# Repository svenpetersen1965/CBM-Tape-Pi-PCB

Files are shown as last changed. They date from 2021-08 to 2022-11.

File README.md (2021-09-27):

# CBM-Tape-Pi-PCB
# Preliminary Release of Rev.2
This is the PCB, that I have created for <a href="https://github.com/RhinoDevel/cbmtapepi">RhinoDevel's CBM Tape Pi</a>.

It is <b>not yet tested</b> and this is only a <b>preliminary</b> release!

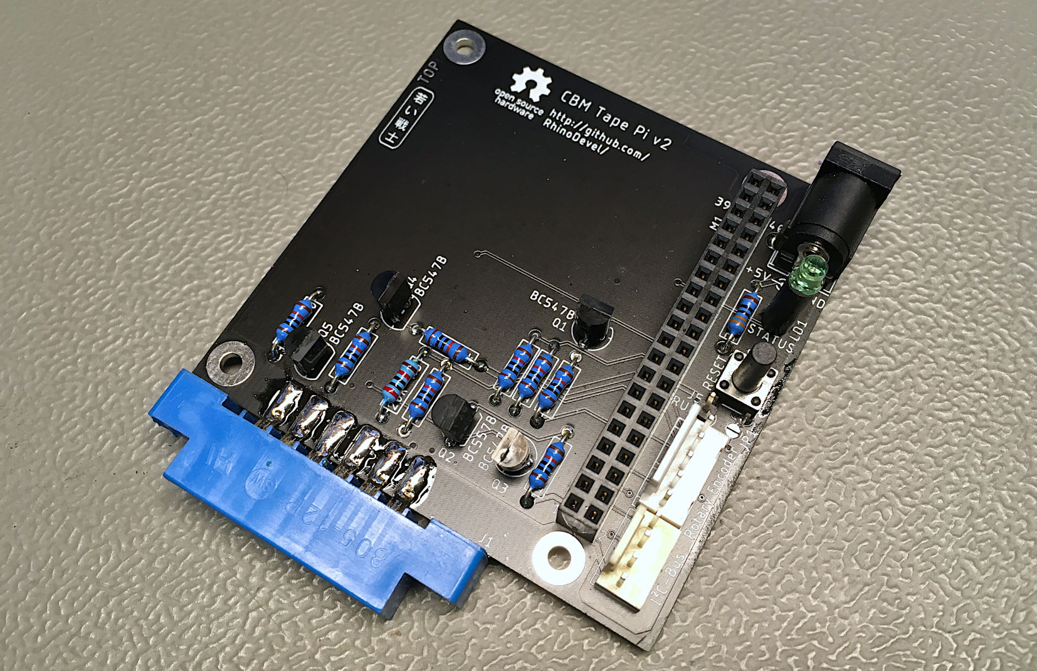
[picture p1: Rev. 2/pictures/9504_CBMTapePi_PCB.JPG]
CBM Tape Pi PCB v2


The PCB has an option for a barrel connector Power Supply. Also, for possible future software development, a rotary encode and an I²C OLED-Display can be connected. This is not yet supported.

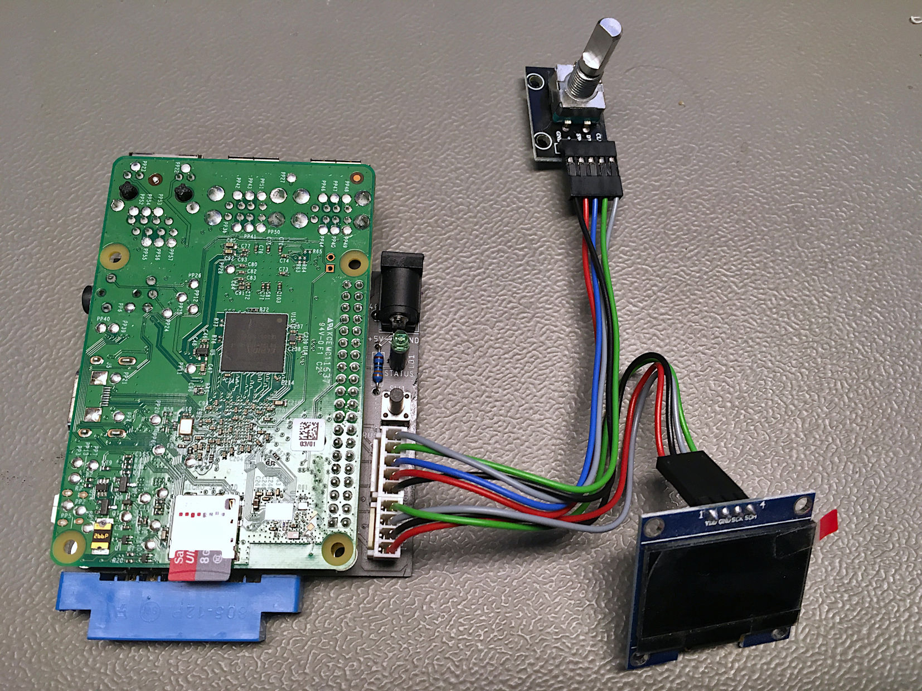
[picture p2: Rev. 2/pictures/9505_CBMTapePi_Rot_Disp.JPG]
CBM Tape Pi PCB complete


Debugging result so far:

There is a screw up with signals <b>BCM11</b>, it shoudl be connected to the collector of Q4, but the signal name is screwed up. A botch wire is required between the collector of Q4/R8 and Pin 23/BCM11 of the Raspberry Pi.

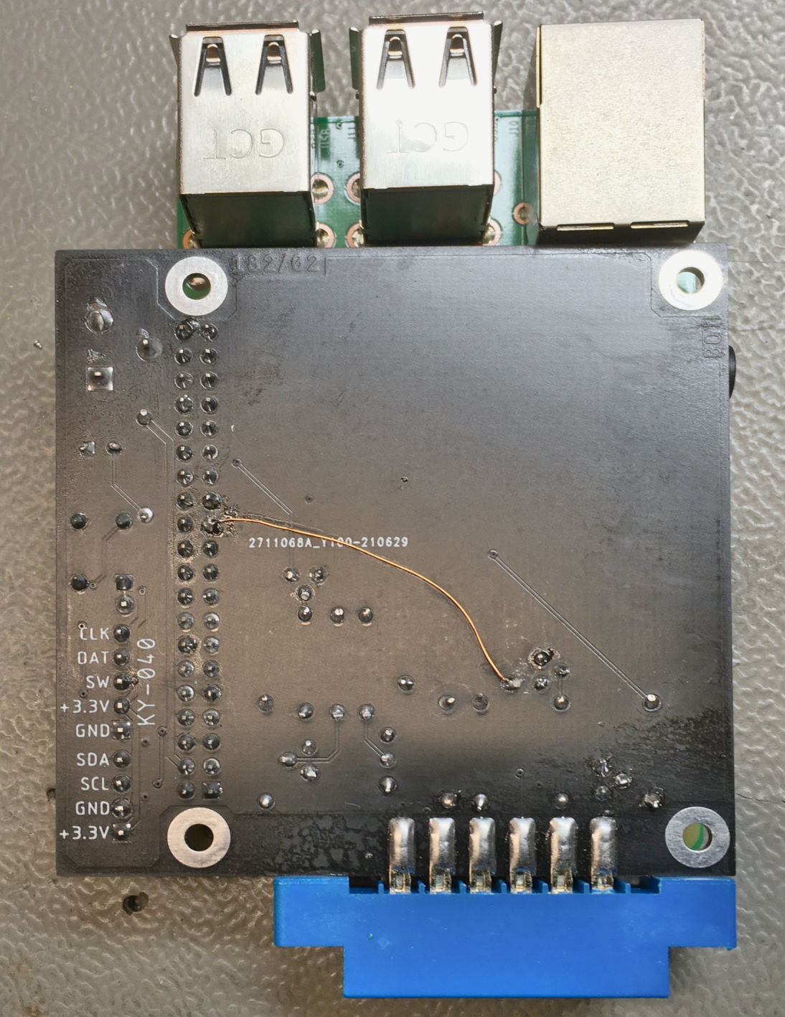
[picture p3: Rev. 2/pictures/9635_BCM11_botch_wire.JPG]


# Rev. 3
Rev. 3 fixes the bug of rev. 2. Also the dimensions have changed: the RasPi was moved 4mm away from the edge connector.

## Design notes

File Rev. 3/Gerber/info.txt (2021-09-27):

      
       Board: CBM_TAPE_PI
       Rev.:  3
  
       Files:
       ======
  
       All Gerber files are generated in extended gerber format (RS274X)
       *.TOP        : Film top copper
       *.BOT        :  -"- bottom copper
       *.STC        :  -"- top soldermask 
       *.STS        :  -"- bottom soldermask
       *.PLC        :  -"- silk screen top
       *.PLS        :  -"- silk screen bottom
       *.DK         : Drills plated Through (Excellon)
       *.NDK        : Drills not plated Through (Excellon)
       *.OUT        : Board outline

       Board Size:
       ===========
       Length     :   67.0 mm
       Width      :   70.0 mm
       Thickness  :   1.6 mm
       Material   :   FR 4
       Copper     :   35 um
       Surface    :   HASL
       
       Remarks:
       ========

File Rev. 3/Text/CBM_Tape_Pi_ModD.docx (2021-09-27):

CBM Tape Pi Rev. 3

Module Description

# Introduction

This is the PCB hardware for RhinoDevel’s CBM Tape Pi project. It is a slight enhancement of the schematic that can be found in his github repository http://github.com/RhinoDevel/

The PCB is suitable to hold a Raspberry Pi *A, *B and zero (three mounting holes on the baseboard).

The Reset button SW1 is connected to J5, a pin header/solder pad for being connected to the RUN connector (pin 1/square pad) on the Raspberry Pi. Since the position is not fix on every model, this can be accomplished with a cable/dupont connector. Alternatively, the Reset button connects to BCM4 (close solder bridge JP1).

The extras are the barrel connector J2 for a Raspberry Pi power supply (it can be used instead of the fragile USB micro-B connector on the Raspberry Pi itself). Alternatively, a pin header or KF2510/Molex kk 2.54 connector can be installed.

For future developments a rotary encoder and an I²C display (+3.3V supply voltage) can be installed. As of September 2021, both are not yet supported. Refer to RhinoDevel’s repository.

# Connectors

## J1 – CBM Cassette Port

2x6 edge connector (3.96mm pitch)

Pin | Signal | Pin | Signal
1 | GND | A | GND
2 | n.c. | B | n.c.
3 | n.c. | C | Motor
4 | n.c. | D | Read
5 | n.c. | E | Write
6 | n.c. | F | Sense

n.c.: not connected

## J2 – Raspberry Pi Power Supply

2.1/5.5mm barrel connector

Pin | Signal
inner | +5V
outer | GND

## J3 – I²C Display

KF2510/Molex KK 2.54mm, 4 pins

Pin | Signal
1 | +3.3V
2 | GND
3 | SCL
4 | SDA

## J4 – Rotary Encode

KF2510/Molex KK 2.54mm, 5 pins

The pin out is according to the wide spread rotary encoder module KY-040, which can be found on ebay, AliExpress and several online shops.

Pin | Signal
1 | GND
2 | +3.3V
3 | Switch
4 | Data
5 | Clock

## J5 – Reset Switch

Pin header, 1 pin

Pin | Signal
1 | /RESET

To be connected to the RUN header on the Raspberry Pi.

## J6 – Alternative Power Supply

KF2510/Molex KK 2.54mm, 2 pins

Pin | Signal
1 | +5V
2 | GND

## M1 -Raspberry Pi Connector

A 2x20 Pin receptible, assembled on the solder side of the PCB.

Pin | GPIO | Signal | Comment
1 | - | +3.3V | Supply voltage (output)
2 | - | +5V | Supply voltage (input)
3 | SDA | SDA (I²C) | I²C-Bus (display)
4 | - | +5V | Supply voltage (input)
5 | SCL | SCL (I²C) | I²C-Bus (display)
6 | - | GND | Ground
7 | 4 | BCM4 | /Reset , Optional (close JP1)
8 | - | n.c. | -
9 | - | GND | Ground
10 | - | n.c. | -
11 | 17 | BCM17 | Status LED (active HIGH)
12 | 18 | n.c. | -
13 | 27 | ROT_SW | Rotary Encoder Switch
14 | - | GND | Ground
15 | 22 | BCM22 | Motor (input)
16 | 23 | ROT_DATA | Rotary Encoder Data
17 | - | +3.3V | Supply voltage (output)
18 | 24 | ROT_CLK | Rotary Encoder Clock
19 | 10 | BCM10 | Read (output, active HIGH)
20 | - | GND | Ground
21 | 9 | BCM9 | Sense (ouput, inverted)
22 | - | n.c. | -
23 | 11 | BCM11 | Write (input, active LOW)
24 | - | n.c. | -
25 | - | GND | Ground
26 | - | n.c. | -
27 | - | n.c. | -
28 | - | n.c. | -
29 | - | n.c. | -
30 | - | GND | Ground
31 | - | n.c. | -
32 | - | n.c. | -
33 | - | n.c. | -
34 | - | GND | Ground
35 | - | n.c. | -
36 | - | n.c. | -
37 | - | n.c. | -
38 | - | n.c. | -
39 | - | GND | Ground
40 | - | n.c. | -

# Revision History

## Rev. 2

- Prototype with one botch wire

## Rev. 3

- Botch wire for BCM11 fixed
- The Raspberry Pi has been moved 4mm away from the edge connector (collision on a VIC-20)
- One mounting hole for Raspberry Pi zero added
- J6 added

CBM_Tape_Pi_ModD.docx 27.09.2021 13:16 Drafted by Sven Petersen Page 2 of 2 Doc.-No.: 182-6-01-03

CBM_Tape_Pi_ModD.docx 27.09.2021 13:16 Drafted by Sven Petersen Page 1 of 1 Doc.-No.: 000-6-00-00

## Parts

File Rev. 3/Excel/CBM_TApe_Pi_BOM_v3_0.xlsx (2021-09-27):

RhinoDevel: CBM Tape Pi Rev. 3
Bill of Material Rev. 3.0
Pos. | Qty | Value | Footprint | Ref.-No. | Comment
1 | 1 | 182-2-01-03 | 2 Layer | PCB Rev. 3 | 2 layer, Cu 35µ, HASL, 70.0mm x 67.0mm, 1.6mm FR4
2 | 1 | 3mm/green | 3MM | LD1 | standard 3mm LED
3 | 1 | KF2510/4p header | 6410-4P | J3 | option: KF2510 or MOLEX 6410/22-27-2041
4 | 1 | KF2510/5p header | 6410-5P | J4 | option: KF2510 or MOLEX 6410/22-27-2051
5 | 8 | 10k | R-10 | R1, R4, R5, R6, R7, R8, R9, R10 | metal film resistor, 10% or better
6 | 1 | 20k | R-10 | R3 | metal film resistor, 10% or better
7 | 1 | 330R | R-10 | R2 | metal film resistor, 10% or better
8 | 1 | KF2510/2p header | 6410-2P | J6 | option: KF2510 or MOLEX 6410/22-27-2021
9 | 4 | BC547B | TO92 | Q1, Q3, Q4, Q5 | NPN Transistor
10 | 1 | BC557B | TO92-EBC | Q2 | PNP Transistror
11 | 1 | 2x6, pitch 3.96mm | TAPEPORT | J1 | edge connector (e.g. 805 type), C64 cassette port
12 | 1 | FCR681465P | FCR681465P | J2 | Cliff, Reichelt: CLIFF FCR681465P, tme.eu: FCR681465P
13 | 1 | JTP-1130 | JTP-1130 | SW1 | 6mm x 6mm tact switch, e.g. Namae Electronics, e.g. Reichelt TASTER 9303
14 | 1 | 1 pin header | 1,2MM_R | J5 | 1 pin header (for dupont wire)
15 | 1 | RASPBERRYPI | PI_HAT_40P_UPSIDEDOWN | M1 | Raspberry Pi zero or other
16 | 1 | MPE 094-2-040 |  | (M1) | MPE, e.g. Reichelt MPE 094-2-040

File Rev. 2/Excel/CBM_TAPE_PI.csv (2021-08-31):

Qty | Value | Device | Package | Parts | Description
1 |  | 3MM | 3MM | LD1
1 |  | 6410-4P | 6410-4P | J3 | 6410/22-27-2041
1 |  | 6410-5P | 6410-5P | J4 | 6410/22-27-2051
1 |  | OPEN | CP_OP | JP1 | open Cutpad
8 | 10k | RES04 | R-10 | R1, R4, R5, R6, R7, R8, R9, R10
1 | 20k | RES04 | R-10 | R3
1 | 330R | RES04 | R-10 | R2
4 | BC547B | BC547B | TO92 | Q1, Q3, Q4, Q5 | NPN Transistor
1 | BC557B | BC557B | TO92-EBC | Q2 | PNP Transistror
1 | C64-TAPEPORT | C64-TAPEPORT | TAPEPORT | J1
1 | FCR681465P | FCR681465P | FCR681465P | J2
1 | JTP-1130 | JTP-1130 | JTP-1130 | SW1
1 | L1,2_R | L1,2_R | 1,2MM_R | J5
1 | OPEN_SOURCE_HW | OPEN_SOURCE_HW | OPENHW | U$2
1 | RASPBERRYPI-40-PIN-GPIOUSDWN | RASPBERRYPI-40-PIN-GPIOUSDWN | PI_HAT_40P_UPSIDEDOWN | M1 | 40 pin GPIO header with the footprint of a HAT

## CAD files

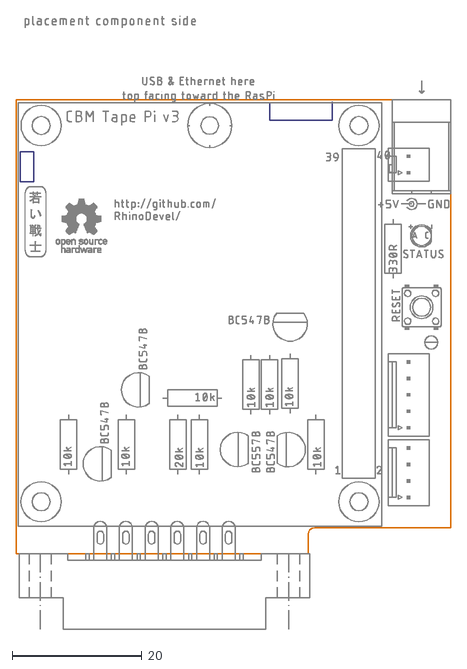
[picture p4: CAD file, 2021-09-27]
Rev. 3/dxf/CBM_TAPE_PI.dxf
67.0 x 94.5

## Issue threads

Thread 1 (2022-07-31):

5VDC Supply requirement / jumper JP1

WimWalther, 2022-07-31:
Could you please leave some comment on the requirement for an external 5VDC power supply, when a regulated 5V is already available on Pin 2 (iirc) of the CBM Cassette Tape port?

I believe jumper JP1 is also undocumented?

Would be much appreciated.

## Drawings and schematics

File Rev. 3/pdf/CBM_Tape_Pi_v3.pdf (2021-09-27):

# Project Documentation

## RhinoDevel: CBM Tape Pi

## Project number: 182

## Revision: 3

## Date: 27.09.2021

CBM_Tape_Pi_ModD.docx | | 27.09.2021 13:16
Drafted by Sven Petersen | Page 1 of 3 | Doc.-No.: 182-6-01-03

### CBM Tape Pi Rev. 3

### Module Description

## Introduction

This is the PCB hardware for RhinoDevel’s CBM Tape Pi project. It is a slight enhancement of the schematic that can be found in his github repository http://github.com/RhinoDevel/

The PCB is suitable to hold a Raspberry Pi *A, *B and zero (three mounting holes on the baseboard).

The Reset button SW1 is connected to J5, a pin header/solder pad for being connected to the RUN connector (pin 1/square pad) on the Raspberry Pi. Since the position is not fix on every model, this can be accomplished with a cable/dupont connector. Alternatively, the Reset button connects to BCM4 (close solder bridge JP1).

The extras are the barrel connector J2 for a Raspberry Pi power supply (it can be used instead of the fragile USB micro-B connector on the Raspberry Pi itself). Alternatively, a pin header or KF2510/Molex kk 2.54 connector can be installed.

For future developments a rotary encoder and an I²C display (+3.3V supply voltage) can be installed. As of September 2021, both are not yet supported. Refer to RhinoDevel’s repository.

## Connectors

### J1 – CBM Cassette Port

2x6 edge connector (3.96mm pitch)

Pin | Signal | Pin | Signal
1 | GND | A | GND
2 | n.c. | B | n.c.
3 | n.c. | C | Motor
4 | n.c. | D | Read
5 | n.c. | E | Write
6 | n.c. | F | Sense
n.c.: not connected

### J2 – Raspberry Pi Power Supply

2.1/5.5mm barrel connector

Pin | Signal
inner | +5V
outer | GND

### J3 – I²C Display

KF2510/Molex KK 2.54mm, 4 pins

Pin Signal
1 +3.3V

### 2 GND 3 SCL 4 SDA

CBM_Tape_Pi_ModD.docx | | 27.09.2021 13:16
Drafted by Sven Petersen | Page 2 of 3 | Doc.-No.: 182-6-01-03

### J4 – Rotary Encode

KF2510/Molex KK 2.54mm, 5 pins

The pin out is according to the wide spread rotary encoder module KY-040, which can be found on ebay, AliExpress and several online shops.

Pin Signal
1 GND
2 +3.3V
3 Switch
4 Data
5 Clock

### J5 – Reset Switch

Pin header, 1 pin

Pin Signal
1 /RESET

To be connected to the RUN header on the Raspberry Pi.

### J6 – Alternative Power Supply

KF2510/Molex KK 2.54mm, 2 pins

Pin Signal
1 +5V
2 GND

### M1 -Raspberry Pi Connector

A 2x20 Pin receptible, assembled on the solder side of the PCB.

Pin | GPIO | Signal | Comment
1 | - | +3.3V | Supply voltage (output)
2 | - | +5V | Supply voltage (input)
3 | SDA | SDA (I²C) | I²C-Bus (display)
4 | - | +5V | Supply voltage (input)
5 | SCL | SCL (I²C) | I²C-Bus (display)
6 | - | GND | Ground
7 | 4 | BCM4 | /Reset , Optional (close JP1)
8 | - | n.c. | -
9 | - | GND | Ground
10 | - | n.c. | -
11 | 17 | BCM17 | Status LED (active HIGH)
12 | 18 | n.c. | -
13 | 27 | ROT_SW | Rotary Encoder Switch
14 | - | GND | Ground
15 | 22 | BCM22 | Motor (input)
16 | 23 | ROT_DATA | Rotary Encoder Data
17 | - | +3.3V | Supply voltage (output)
18 | 24 | ROT_CLK | Rotary Encoder Clock
19 | 10 | BCM10 | Read (output, active HIGH)

CBM_Tape_Pi_ModD.docx | | 27.09.2021 13:16
Drafted by Sven Petersen | Page 3 of 3 | Doc.-No.: 182-6-01-03
Pin | GPIO | Signal | Comment
20 | - | GND | Ground
21 | 9 | BCM9 | Sense (ouput, inverted)
22 | - | n.c. | -
23 | 11 | BCM11 | Write (input, active LOW)
24 | - | n.c. | -
25 | - | GND | Ground
26 | - | n.c. | -
27 | - | n.c. | -
28 | - | n.c. | -
29 | - | n.c. | -
30 | - | GND | Ground
31 | - | n.c. | -
32 | - | n.c. | -
33 | - | n.c. | -
34 | - | GND | Ground
35 | - | n.c. | -
36 | - | n.c. | -
37 | - | n.c. | -
38 | - | n.c. | -
39 | - | GND | Ground
40 | - | n.c. | -

## Revision History

### Rev. 2

- Prototype with one botch wire
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

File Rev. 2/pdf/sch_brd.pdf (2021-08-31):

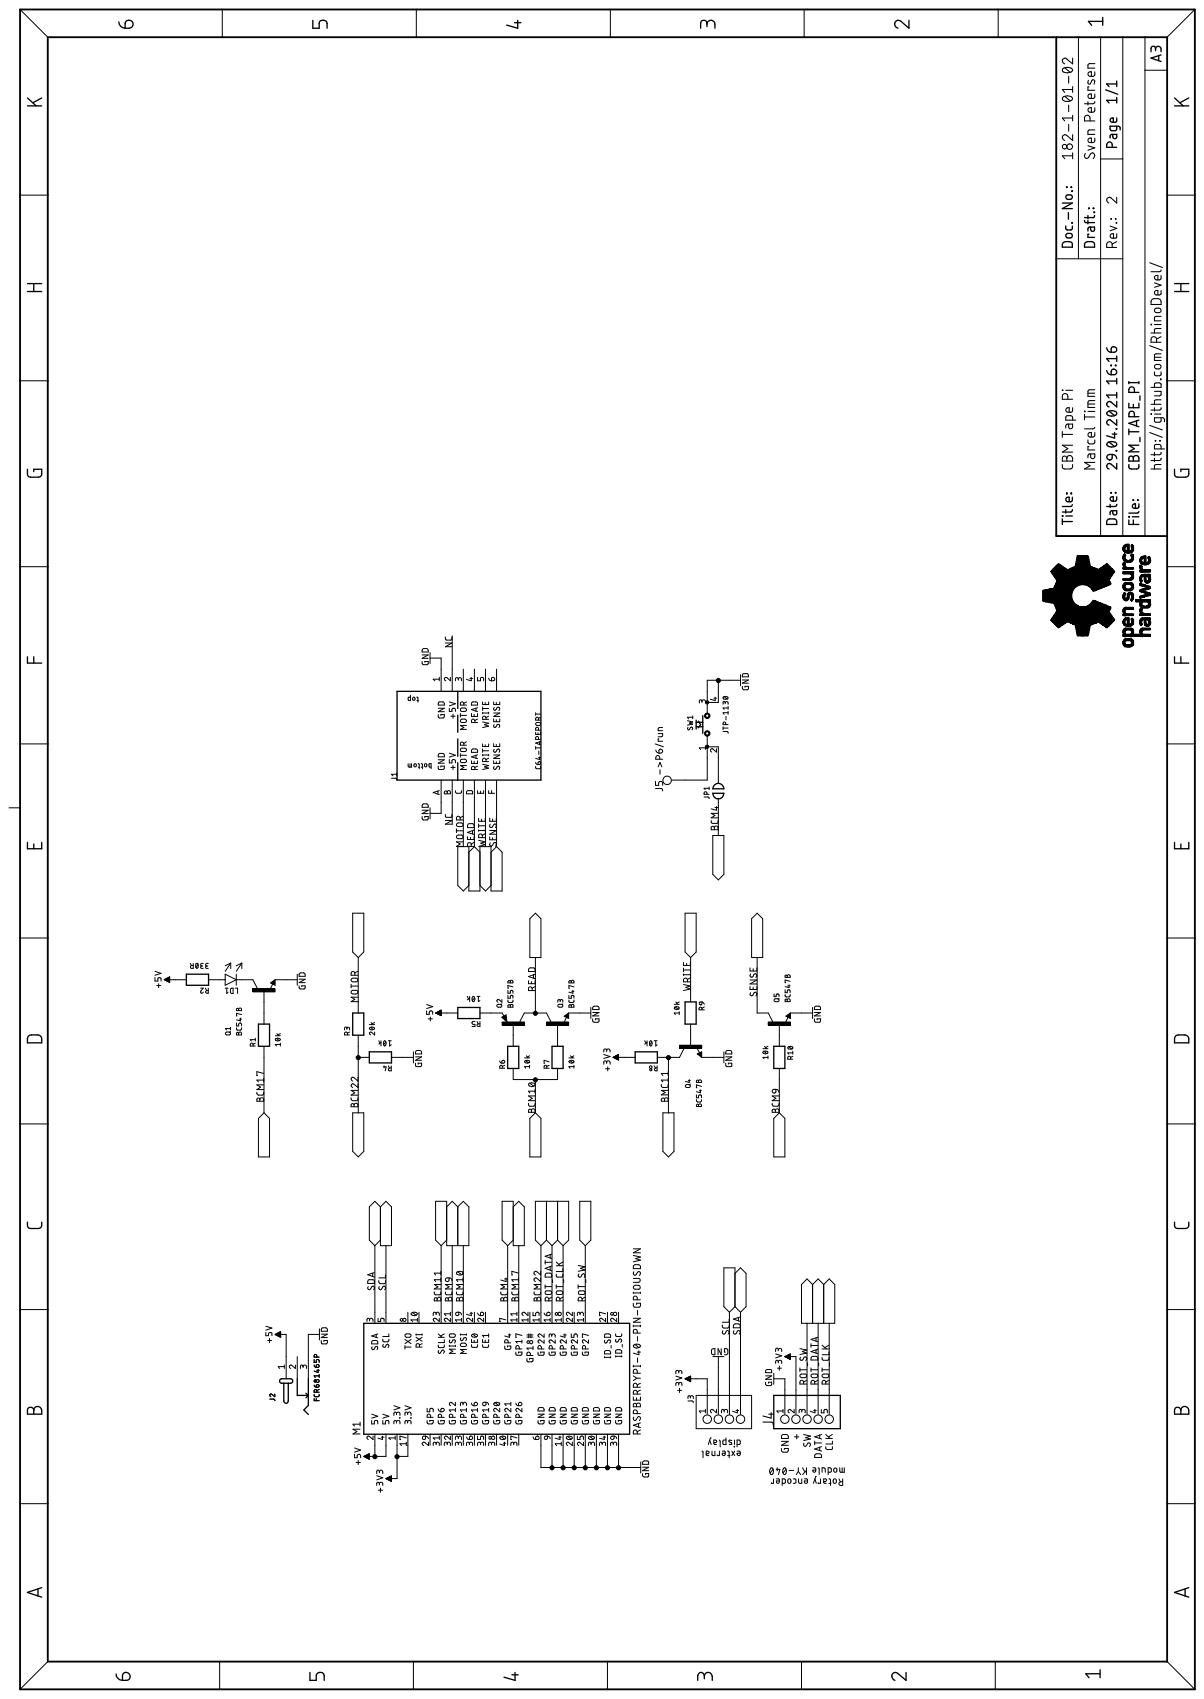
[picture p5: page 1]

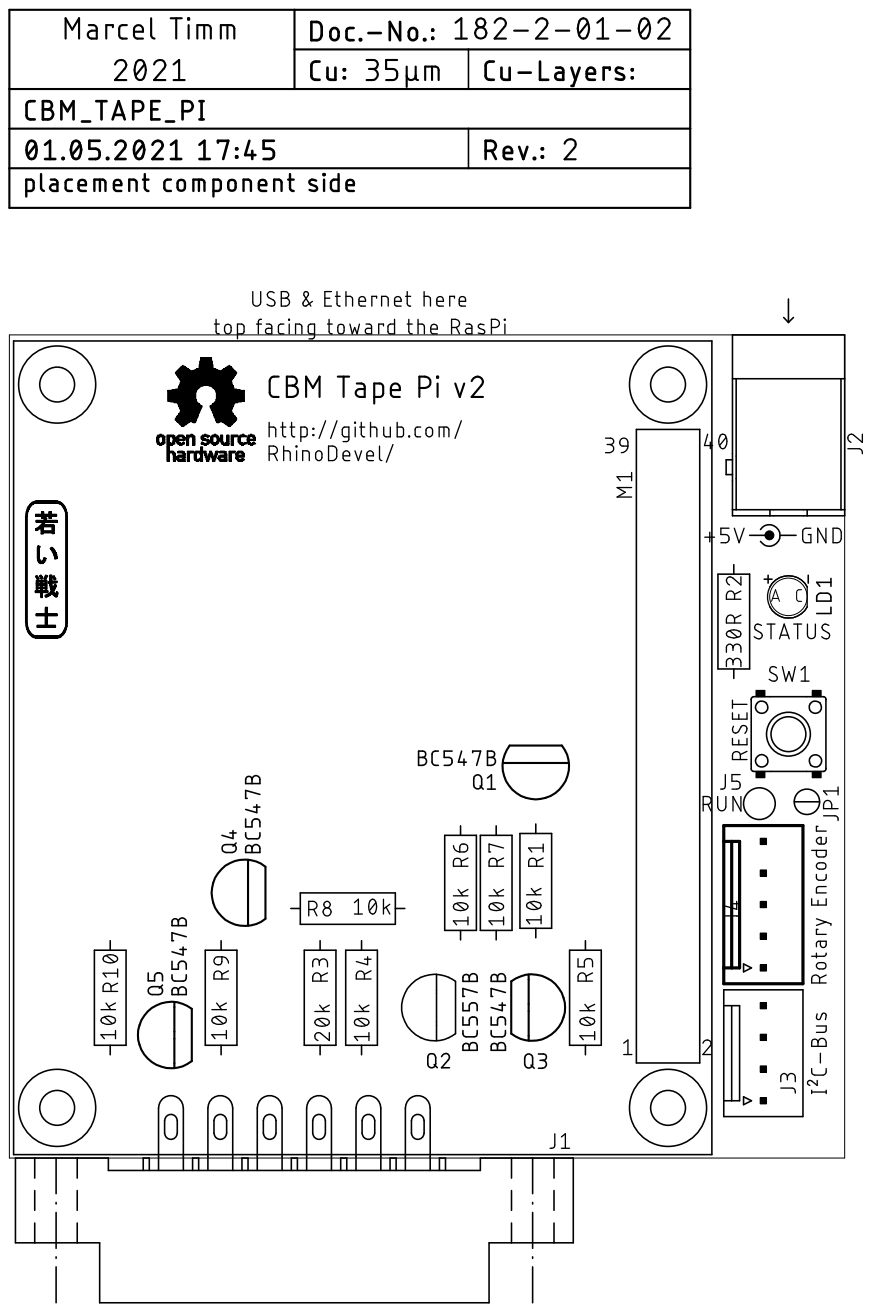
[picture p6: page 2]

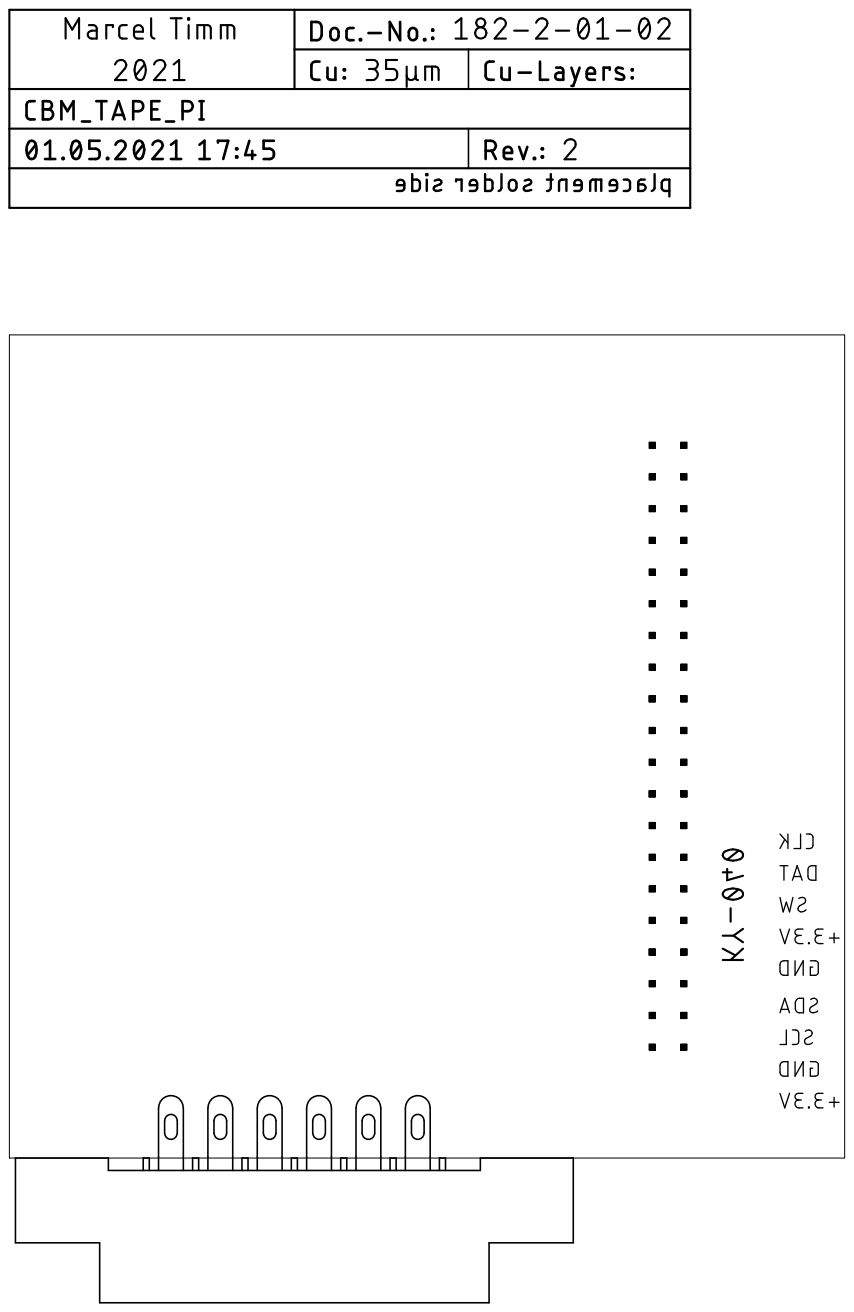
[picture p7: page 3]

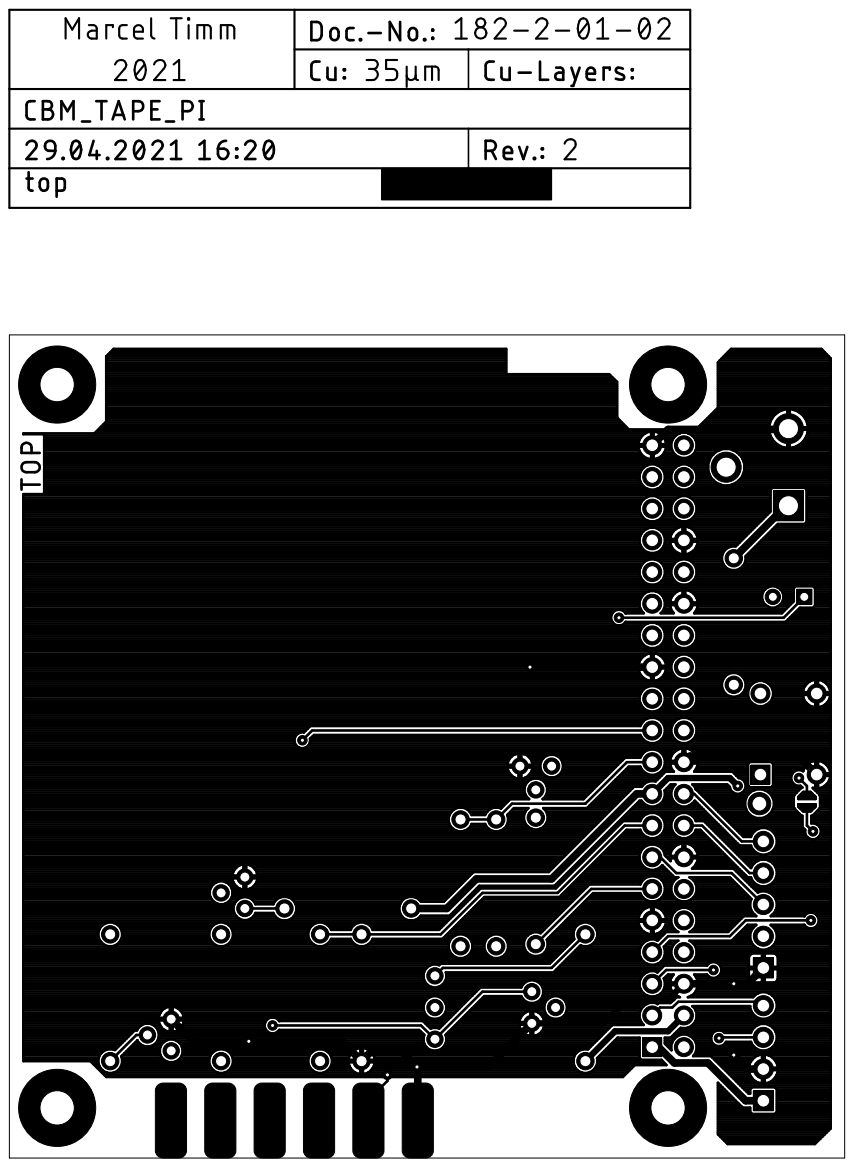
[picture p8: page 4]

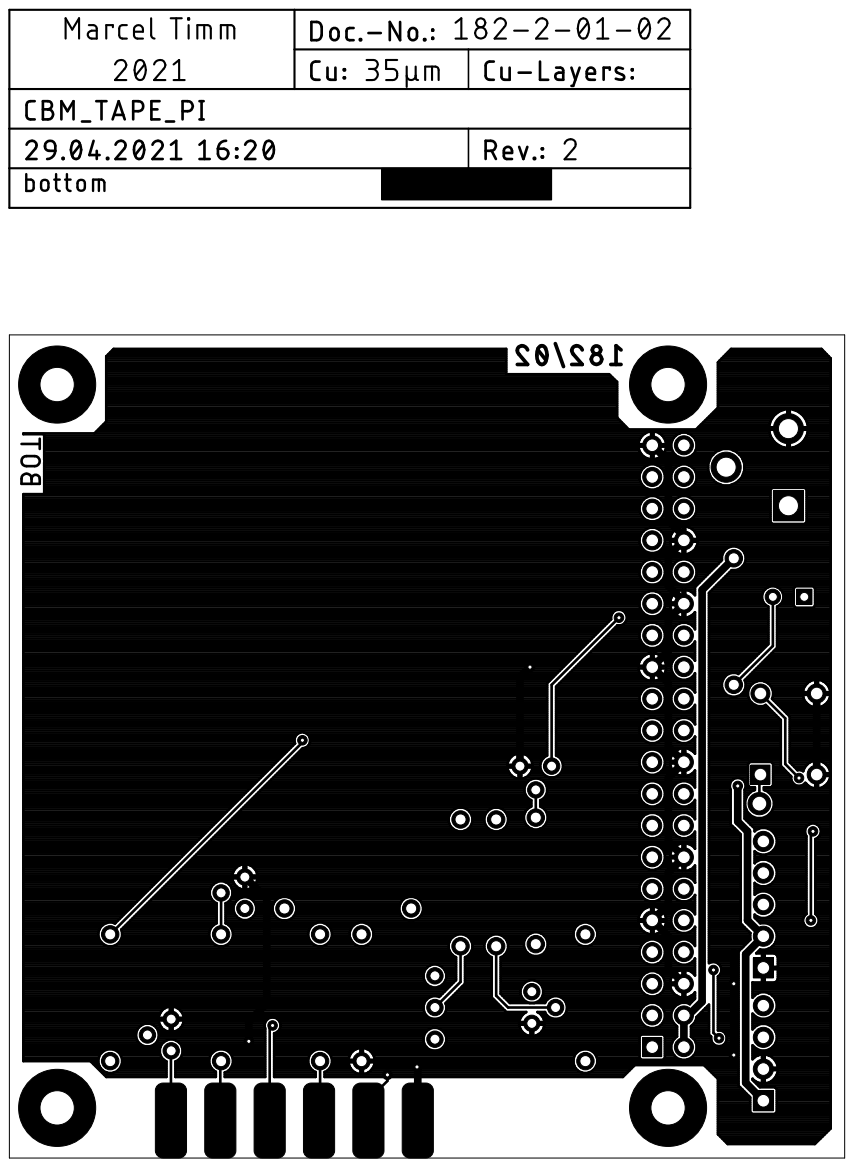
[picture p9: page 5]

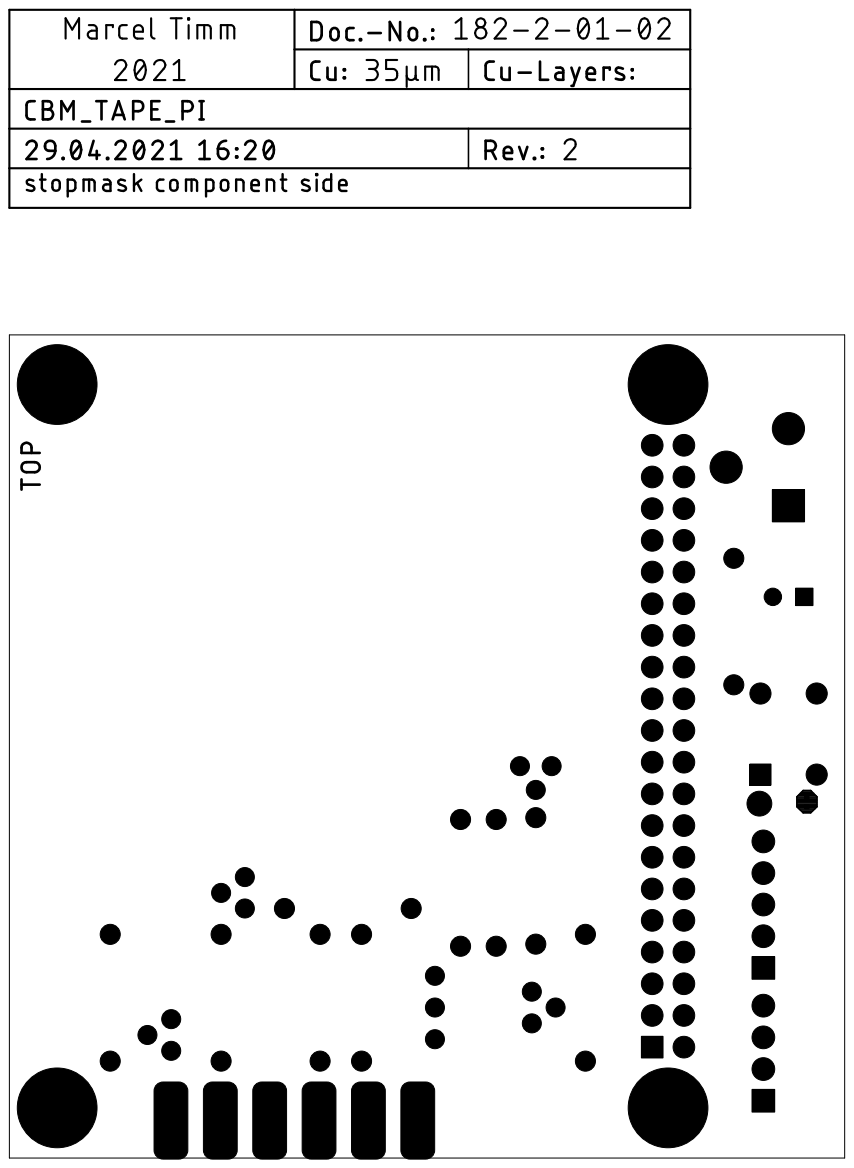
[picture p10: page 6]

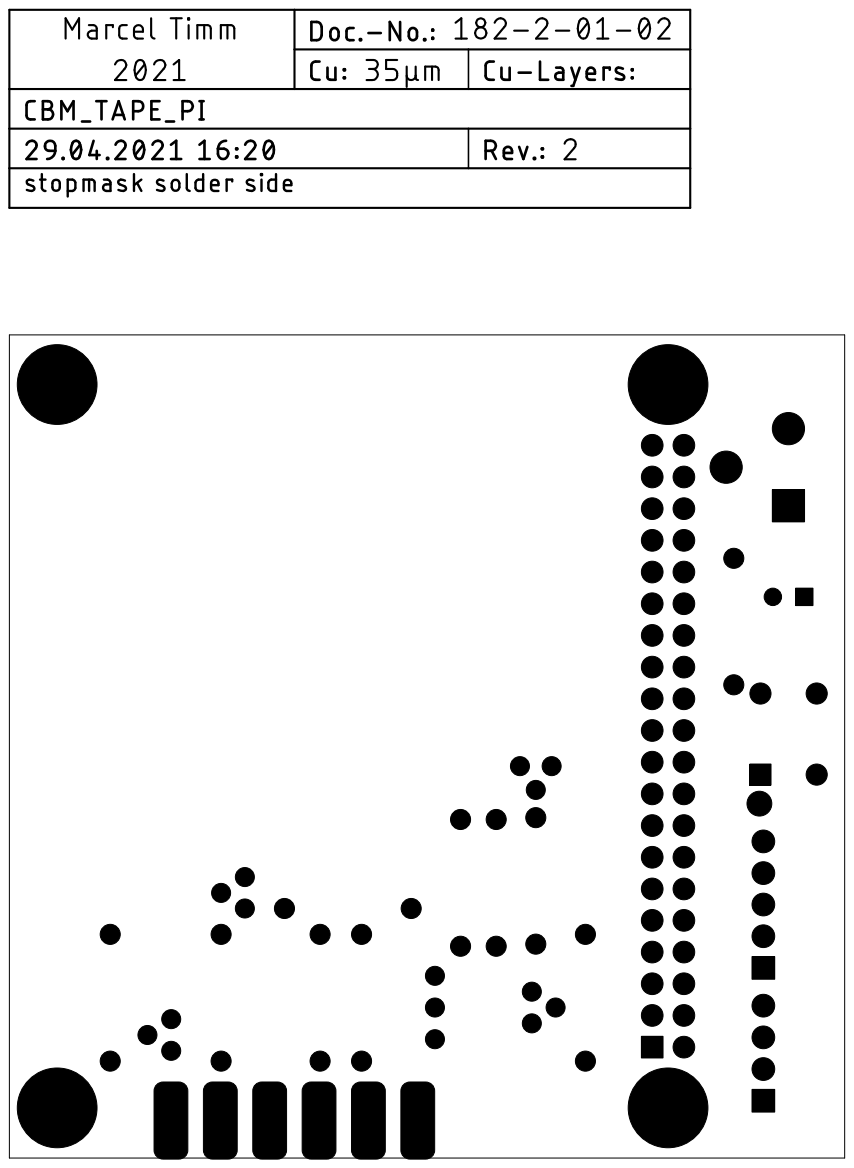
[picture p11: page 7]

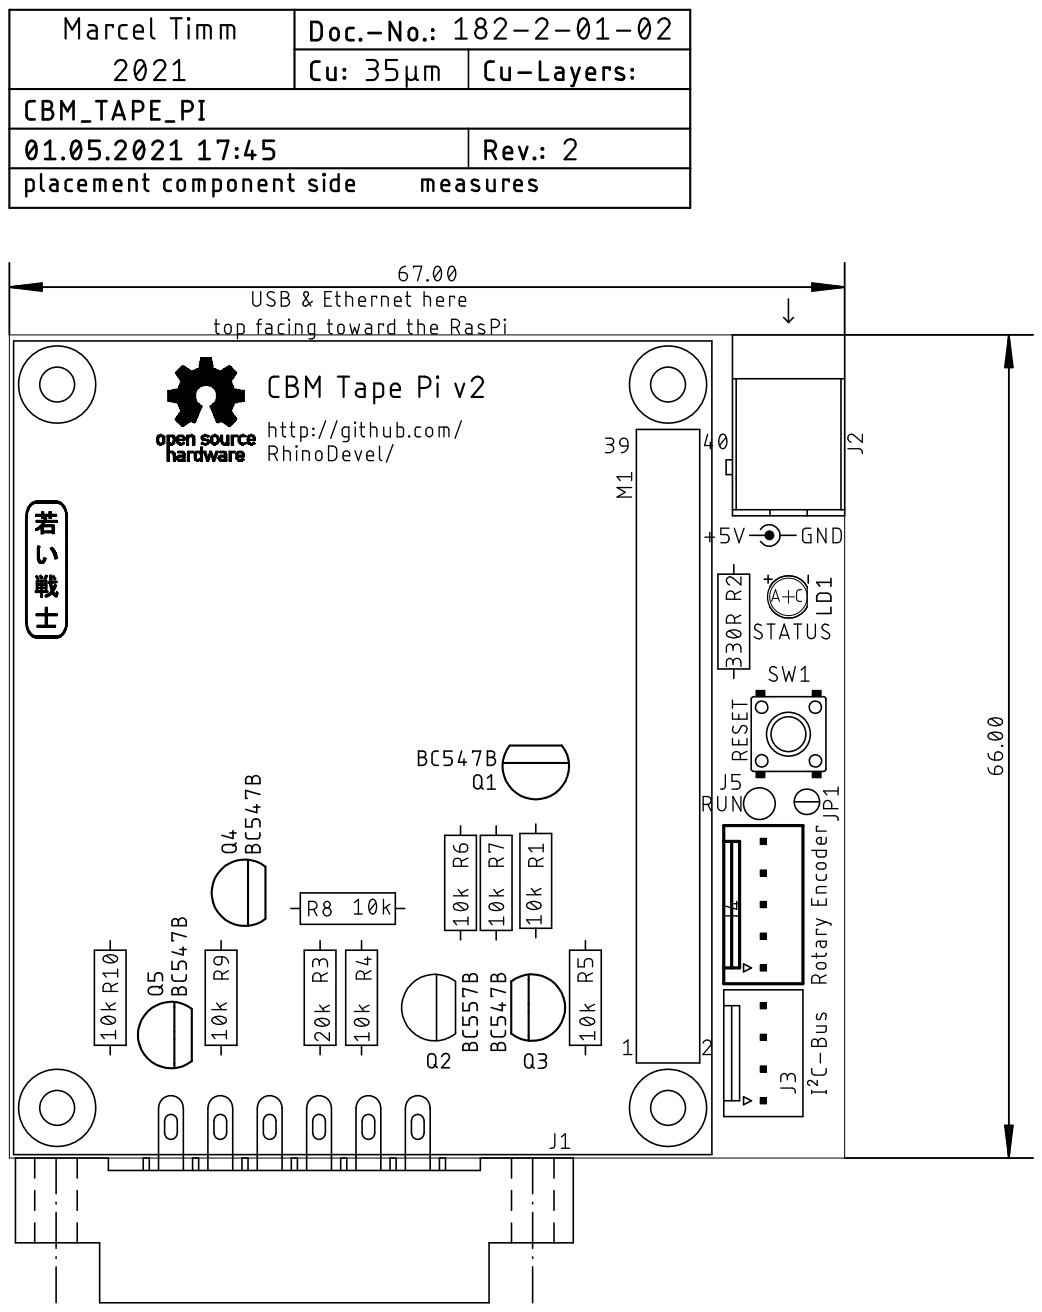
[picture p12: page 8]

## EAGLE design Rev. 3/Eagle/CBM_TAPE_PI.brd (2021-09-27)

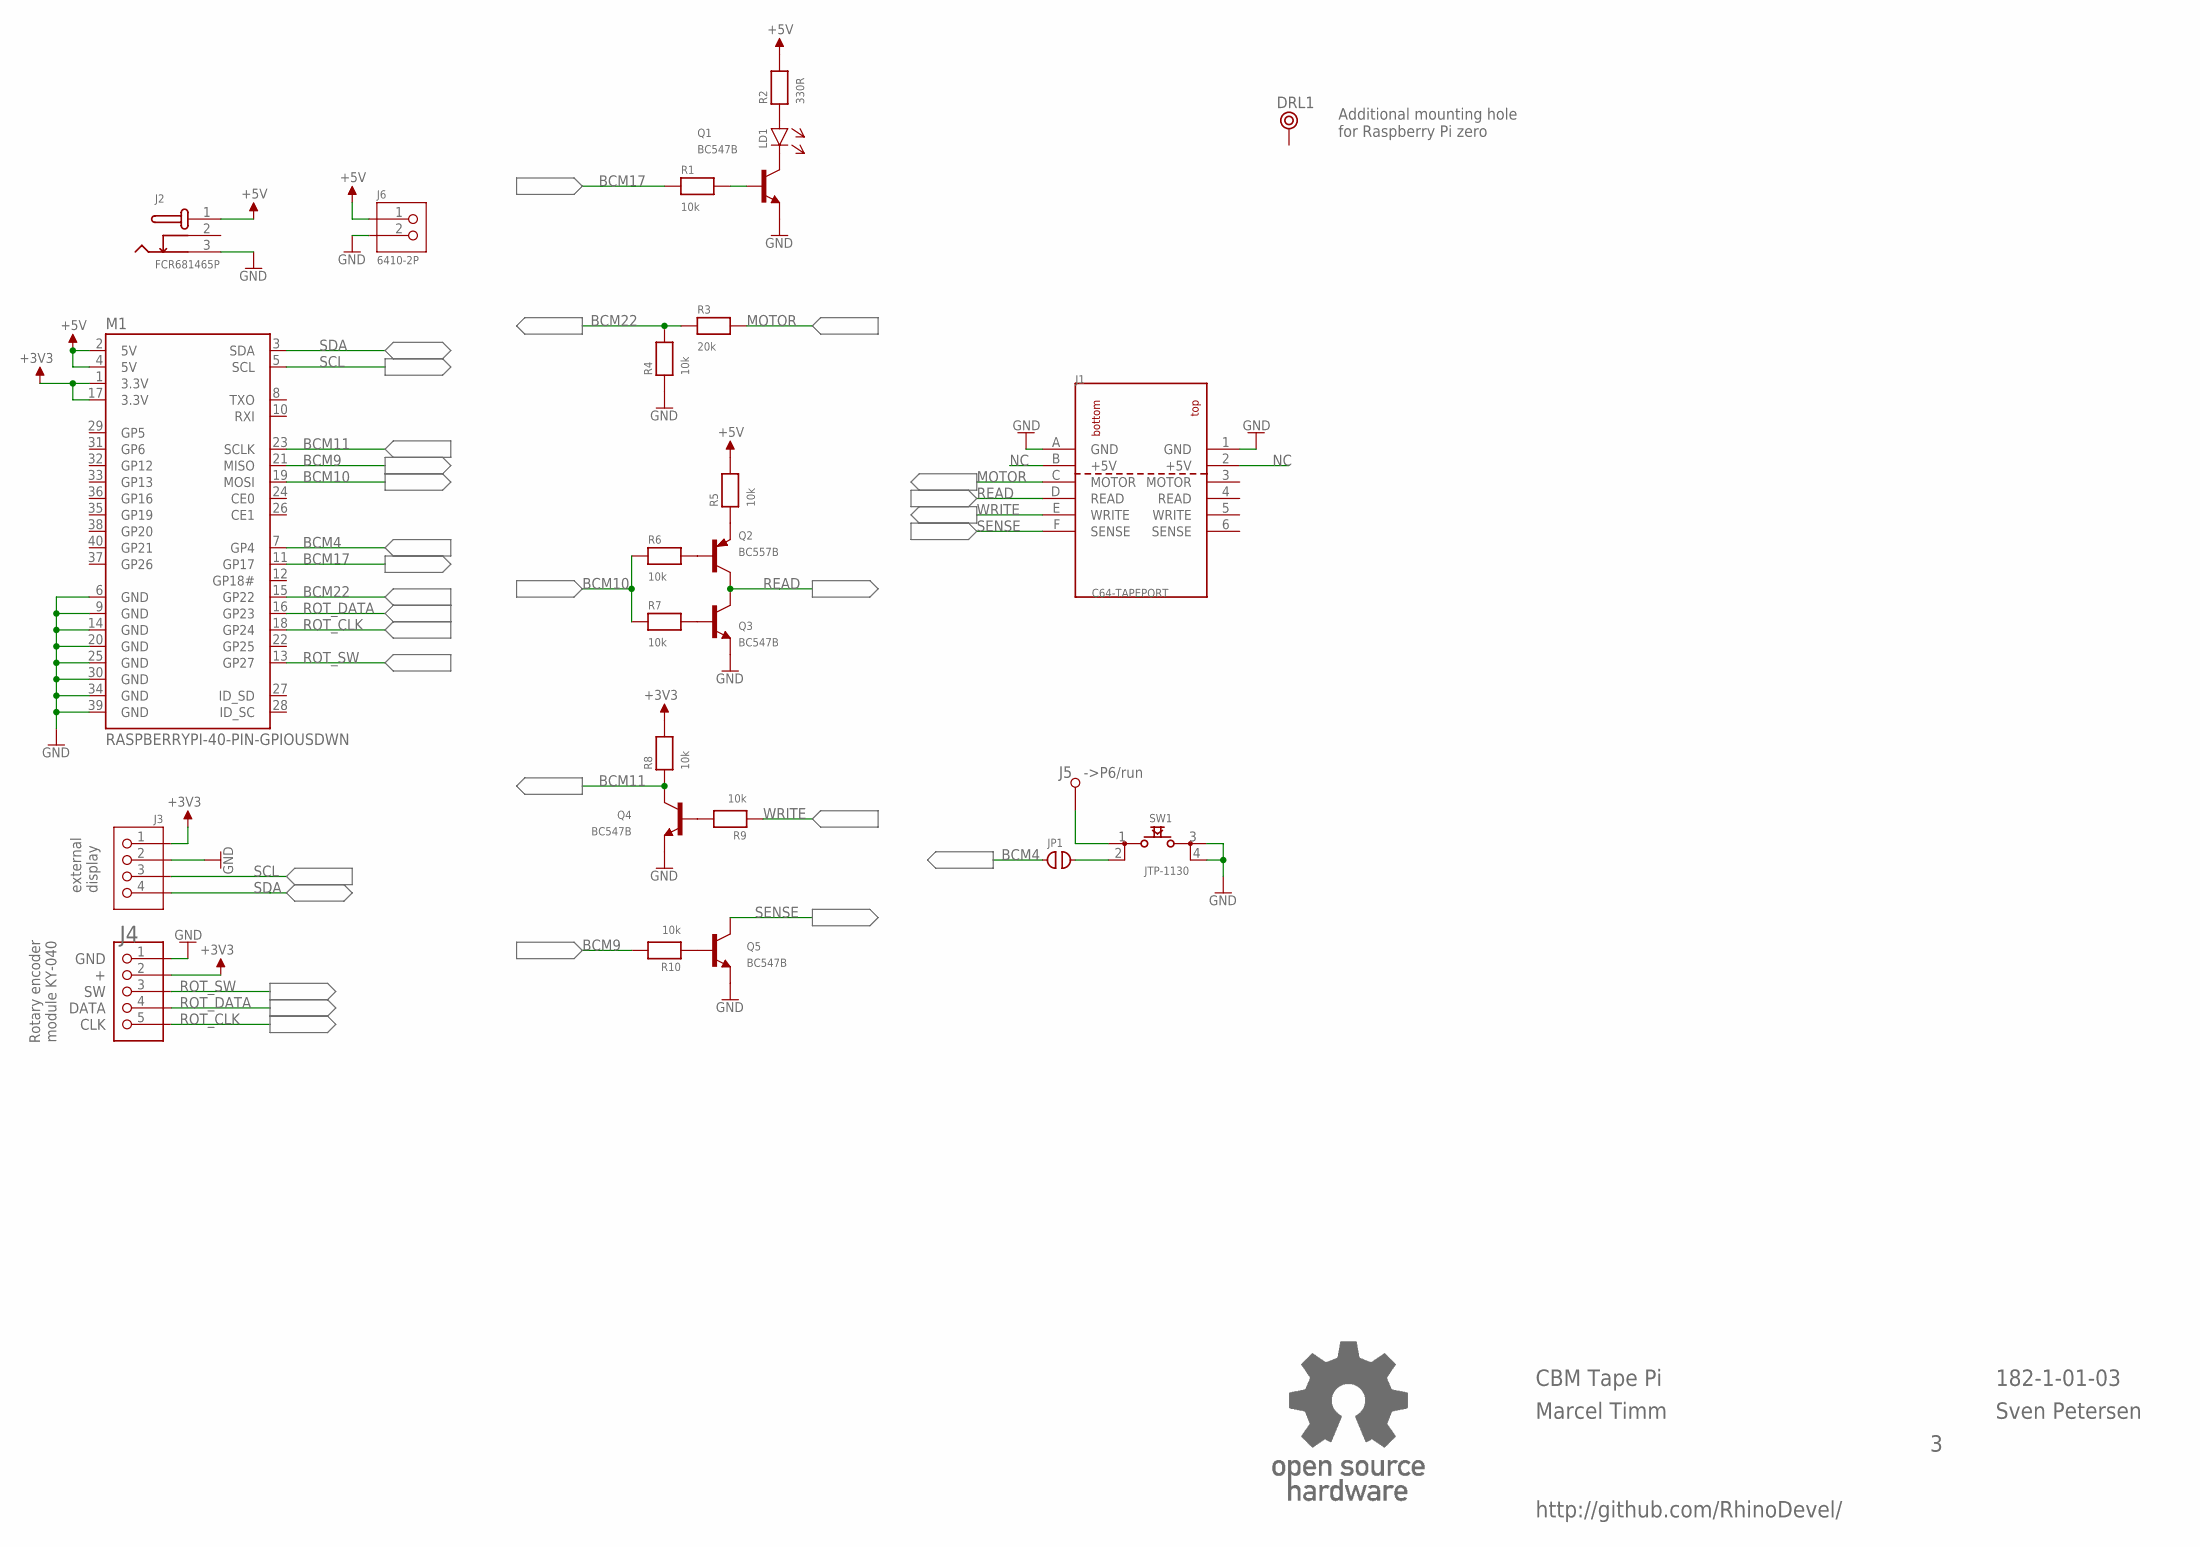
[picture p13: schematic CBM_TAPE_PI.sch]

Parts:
DRL1: RPI_MNT; RASPI_MNT
J1: C64-TAPEPORT; TAPEPORT
J2: FCR681465P
J3: 6410-4P
J4: 6410-5P
J5: L1,2_R; 1,2MM_R
J6: 6410-2P
JP1: OPEN; CP_OP
LD1: 3MM
M1: RASPBERRYPI-40-PIN-GPIOUSDWN; PI_HAT_40P_UPSIDEDOWN
Q1, Q3, Q4, Q5: BC547B; TO92
Q2: BC557B; TO92-EBC
R1, R4, R5, R6, R7, R8, R9, R10: 10k; R-10
R2: 330R; R-10
R3: 20k; R-10
SW1: JTP-1130
U$2: OPEN_SOURCE_HW; OPENHW

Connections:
+3V3: J3.1, J4.2, M1.1 (3.3V), M1.17 (3.3V), R8.2
+5V: J2.1, J6.1, M1.2 (5V), M1.4 (5V), R2.2, R5.2
BCM4: JP1.1, M1.7 (GP4)
BCM9: M1.21 (MISO), R10.2
BCM10: M1.19 (MOSI), R6.1, R7.1
BCM11: M1.23 (SCLK), Q4.3 (C), R8.1
BCM17: M1.11 (GP17), R1.1
BCM22: M1.15 (GP22), R3.1, R4.2
GND: J1.1 (GND), J1.A (GND), J2.3, J3.2, J4.1, J6.2, M1.6 (GND), M1.9 (GND), M1.14 (GND), M1.20 (GND), M1.25 (GND), M1.30 (GND), M1.34 (GND), M1.39 (GND), Q1.1 (E), Q3.1 (E), Q4.1 (E), Q5.1 (E), R4.1, SW1.3, SW1.4
MOTOR: J1.C (MOTOR), R3.2
unnamed: Q1.2 (B), R1.2
unnamed: LD1.C (K), Q1.3 (C)
unnamed: LD1.A, R2.1
unnamed: Q2.E, R5.1
unnamed: Q2.B, R6.2
unnamed: Q3.2 (B), R7.2
unnamed: Q4.2 (B), R9.2
unnamed: Q5.2 (B), R10.1
unnamed: J5.1, SW1.1
unnamed: JP1.2, SW1.2
NC: J1.2 (+5V), J1.B (+5V)
READ: J1.D (READ), Q2.C, Q3.3 (C)
ROT_CLK: J4.5, M1.18 (GP24)
ROT_DATA: J4.4, M1.16 (GP23)
ROT_SW: J4.3, M1.13 (GP27)
SCL: J3.3, M1.5 (SCL)
SDA: J3.4, M1.3 (SDA)
SENSE: J1.F (SENSE), Q5.3 (C)
WRITE: J1.E (WRITE), R9.1

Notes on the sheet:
http://github.com/RhinoDevel/
CBM Tape Pi
Sven Petersen
external display
GND
DATA
CLK
Rotary encoder module KY-040
->P6/run
Marcel Timm
182-1-01-03
Additional mounting hole for Raspberry Pi zero

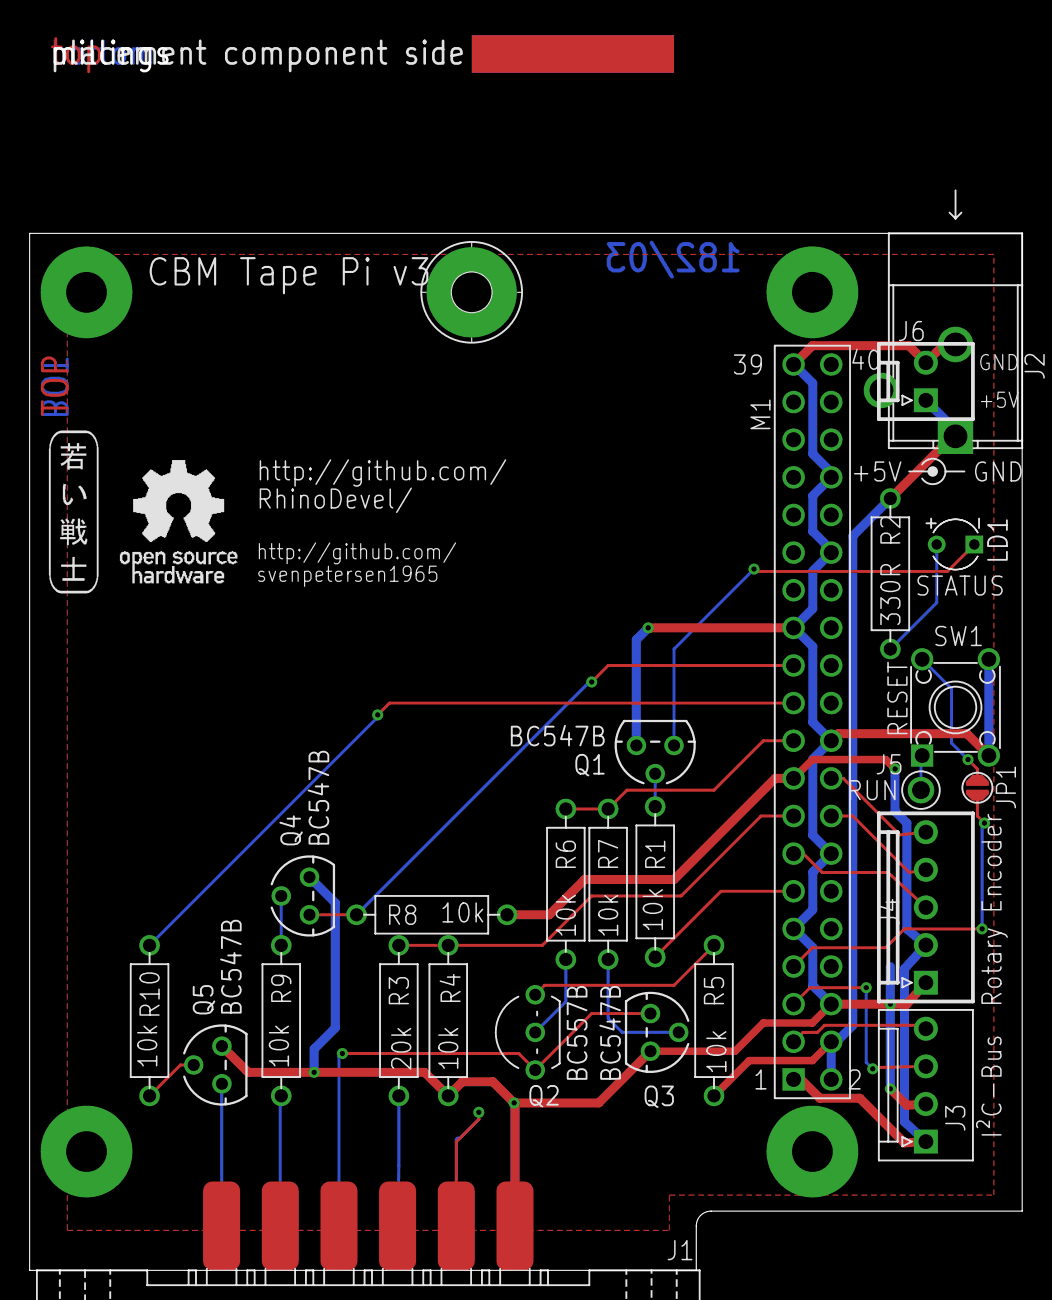
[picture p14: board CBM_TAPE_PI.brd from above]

Board: 2 copper layers, 67.0 x 70.0 mm, 30 parts (0 on the bottom side), 29 nets.

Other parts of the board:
U$53: 2LAYER
U$54: SVEN_TAG
U$55: PCB-TITLE/

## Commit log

2021-08-31 Preliminary Release
    This is released untested!
    [CBM_TAPE_PI.brd, CBM_TAPE_PI.csv, CBM_TAPE_PI.sch]
2021-09-13 BCM11 botch wire
